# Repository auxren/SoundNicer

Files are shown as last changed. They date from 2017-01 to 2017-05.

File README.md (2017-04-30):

# SoundNicer
Eurorack Sound Nicer Module:

Maximizes the sonic potention of your modular signals.
Simple input and output with process and contour knobs.
Based off the CoolAudio V2153M

Version 1.1 Changes:
Changed resistor values to prevent clipping of incoming audio
Changed the potentiometer values and series resistors. Anything past 2'oclock starts to add distortion to the band.

Mouser cart: http://www.mouser.com/ProjectManager/ProjectDetail.aspx?AccessID=db3011bba3 
Still needs V2153, pots, and jacks.

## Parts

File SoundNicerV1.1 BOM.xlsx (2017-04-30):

Description | Designator | Distributor | Distributor_Pn | Mfr_Pn | Quantity | Comment
CAP | C1 | Mouser | 581-06032A101JAT2A | 06032A101JAT2A | 1 | 100pF
CAP | C2, C8, C9 | Mouser | 81-GRM188R61E225KA2D | GRM188R61E225KA12D | 3 | 2.2uF
CAP | C3 | Mouser | 581-06035A332JAT2A | 06035A332JAT2A | 1 | 3.3nF
CAP | C4, C6, C7 | Mouser | 81-GCM188R71E474KA4J | GCM188R71E474KA64J | 3 | 0.47uF
CAP | C5 | Mouser | 81-GRM188R71H333KA61 | GRM188R71H333KA61D | 1 | 33nF
CAP | C10, C12, C14, C15, C16 | Mouser | 581-MM035C104KCZ2A | MM035C104KCZ2A | 5 | 100nF
Aluminum Electrolytic Capacitor, UD Series, Low Impedance, 10 uF, 25 V, + / - 20%, -55 to 105 degC, Chip Type, 4 x 5.8 mm D x L, Pb-Free, Reel | C11, C13 | Mouser | 647-UUD1E100MCL | UUD1E100MCL1GS | 2 | 10uF
1.0 A Surface Mount Schottky Barrier Rectifier, 40 V, -65 to 125 degC, 2-Pin SOD-123 Package, RoHS, Tape and Reel | D1, D2 | Mouser | 621-1N5819HW-F | 1N5819HW-7-F | 2 | 1N5819HW-7-F
 | J1, J2 | Thonk |  |  | 2 | Thonkicon jack
Header, 5-Pin, Dual row | P1 | Mouser | 855-M20-9980545 |  | 1 | Header 5X2
Res | R1, R2, R7, R9, R10, R11, R12, R13, R14 | Mouser | 754-RG1608P-2152DT5 | RG1608P-2152-D-T5 | 9 | 21.5k
Res | R3, R4 | Mouser | 754-RR0816P-821D | RR0816P-821-D | 2 | 820
Res | R5 | Mouser | 754-RR0816P-103D | RR0816P-103-D | 1 | 10k
Res | R6 | Mouser | 754-RR0816P-1822D26C | RR0816P-1822-D-26C | 1 | 18.2k
Res | R8 | Mouser | 660-RK73H1JTTD3922F | RK73H1JTTD3922F | 1 | 39.2k
Res | R15 | Mouser | 660-RN73H1JT1062D100 | RN73H1JTTD1062D100 | 1 | 10.6k
Res | R16, R19 | Mouser | 754-RR0816P-753D | RR0816P-753D | 2 | 75k
Res | R17, R18 | Mouser | 754-RR0816P-104D | RR0816P-104-D | 2 | 100k
V2153 | U1 | Small Bear |  |  | 1 | V2153 Sound Enhancement IC
Dual Low-Noise JFET-Input General-Purpose Operational Amplifier, 7 to 36 V, -40 to 85 degC, 8-pin SOIC (D8), Green (RoHS & no Sb/Br) | U2 | Mouser | 511-TL072IDT | TL072IDT | 1 | TL072ID
Thonk Pot | VR1, VR2 |  |  |  | 2 | B10k

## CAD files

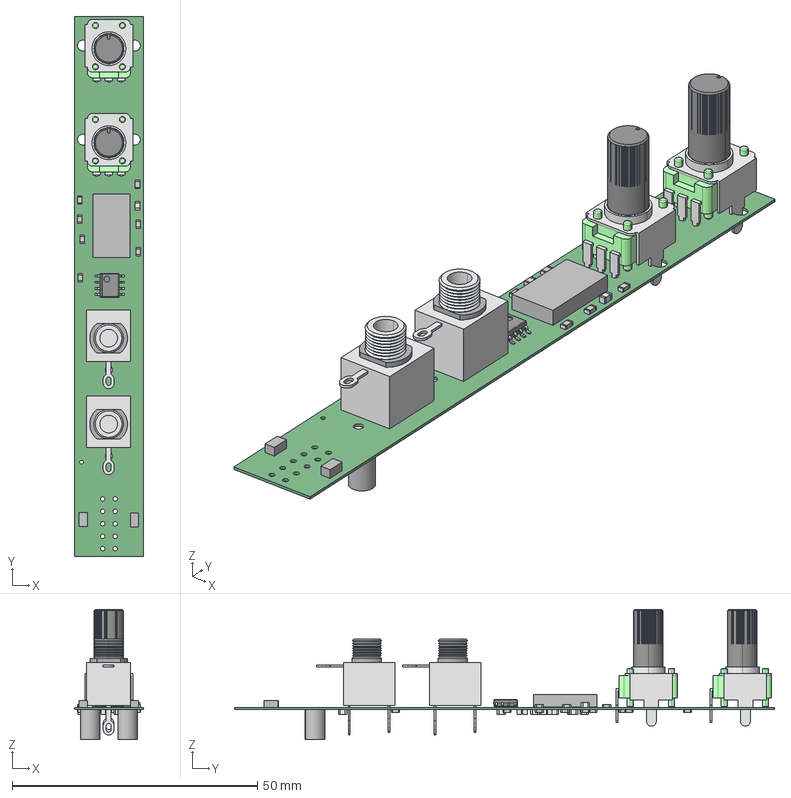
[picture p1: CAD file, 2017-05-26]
Sound Nicer Altium Project/SoundNicerPCB.step
14.2 x 110.2 x 26.5 mm
Board
9mmAlpha x 2
BODY_M08A_35
LEAD_M08A_57 x 8
MANIFOLD_SOLID_BREP_2784
MANIFOLD_SOLID_BREP_2935
MANIFOLD_SOLID_BREP_3086
MANIFOLD_SOLID_BREP_3237
Extruded x 102
mj-3507 x 2

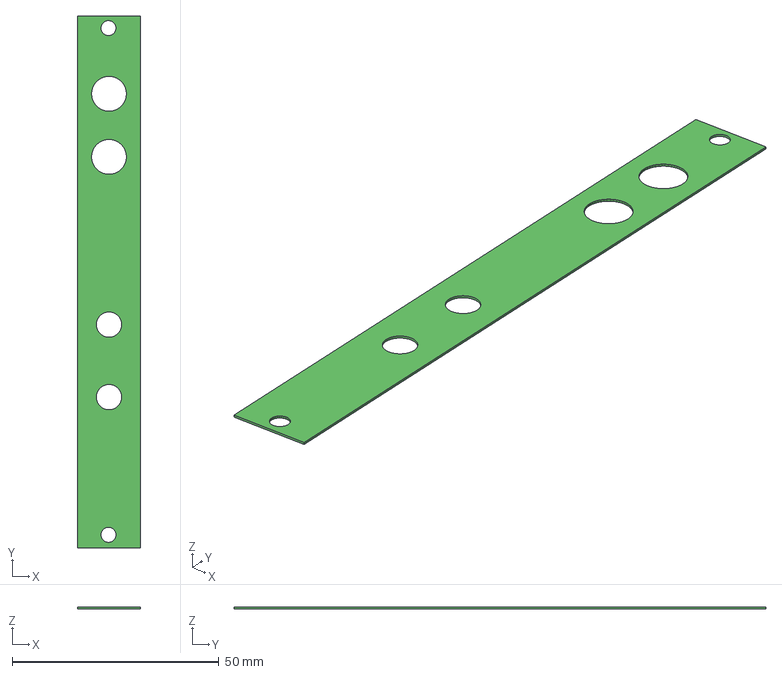
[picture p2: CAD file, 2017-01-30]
SoundNicerPanel/SoundNicerPanel.step
15.2 x 128.5 x 0.411 mm

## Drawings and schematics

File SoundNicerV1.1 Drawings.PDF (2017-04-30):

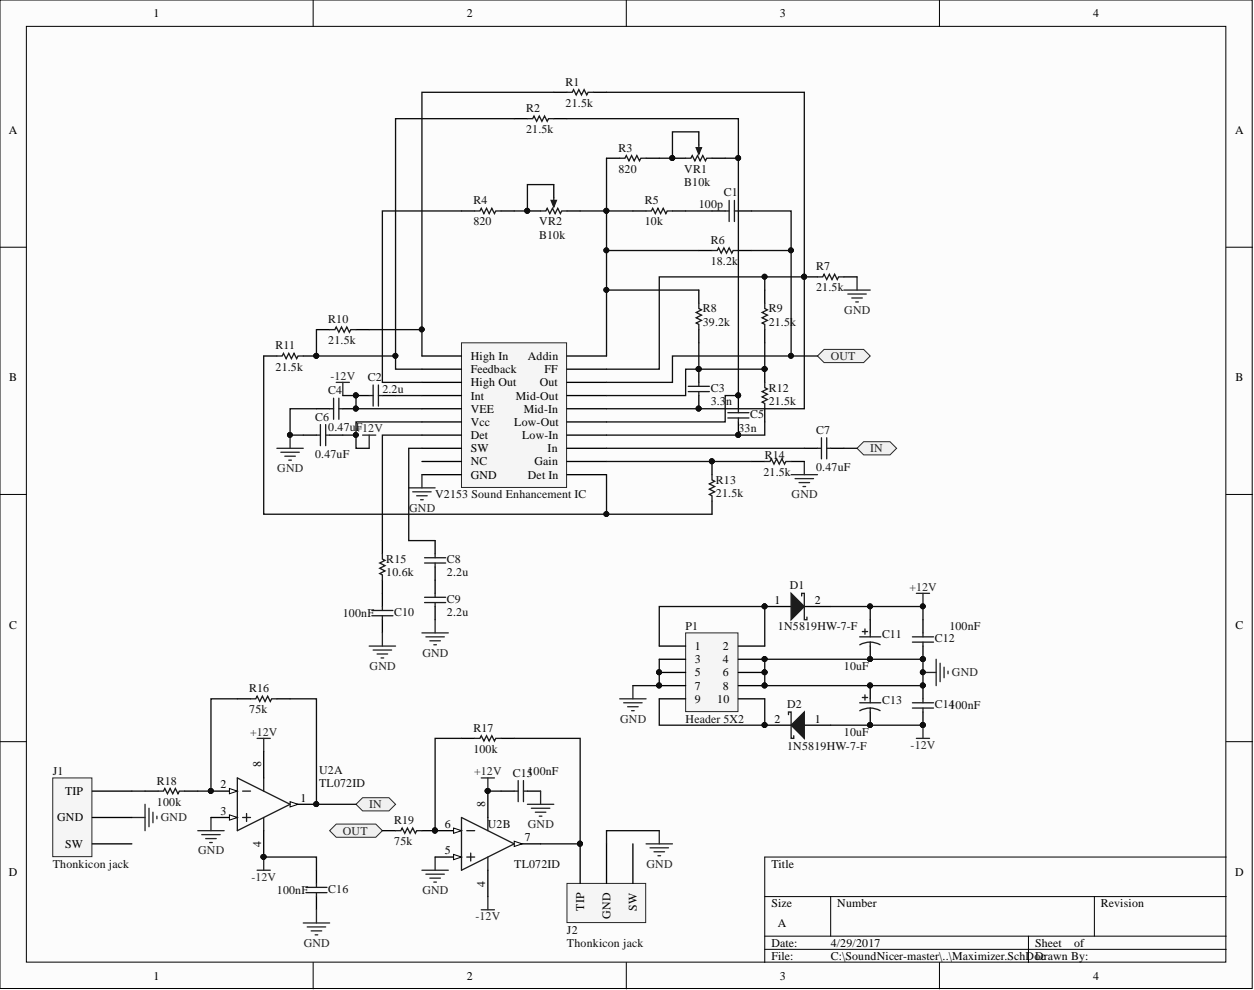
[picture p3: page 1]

High In

Out Mid-Out Mid-In Low-Out Low-In In Gain Det In

High Out Int VEE Vcc Det SW NC GND | | R12 21.5k

GND

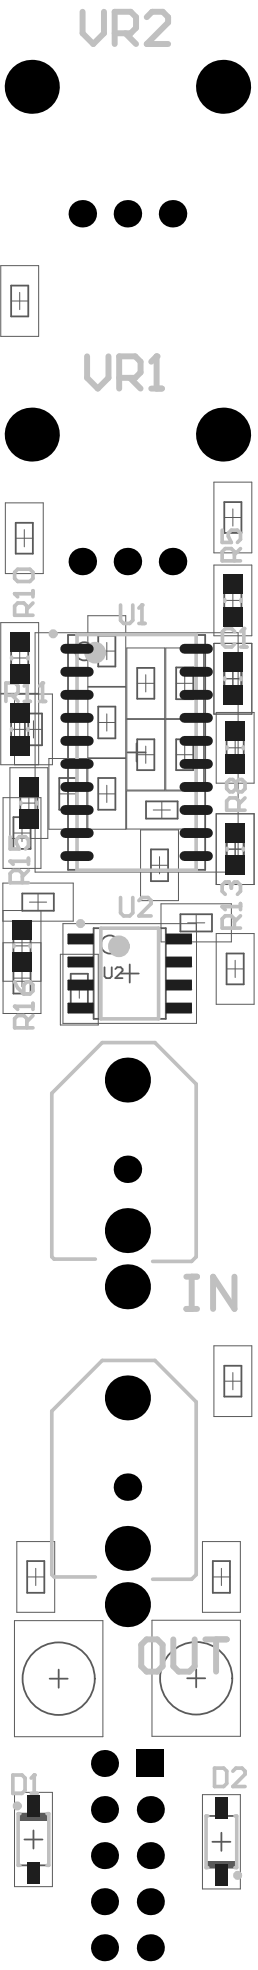
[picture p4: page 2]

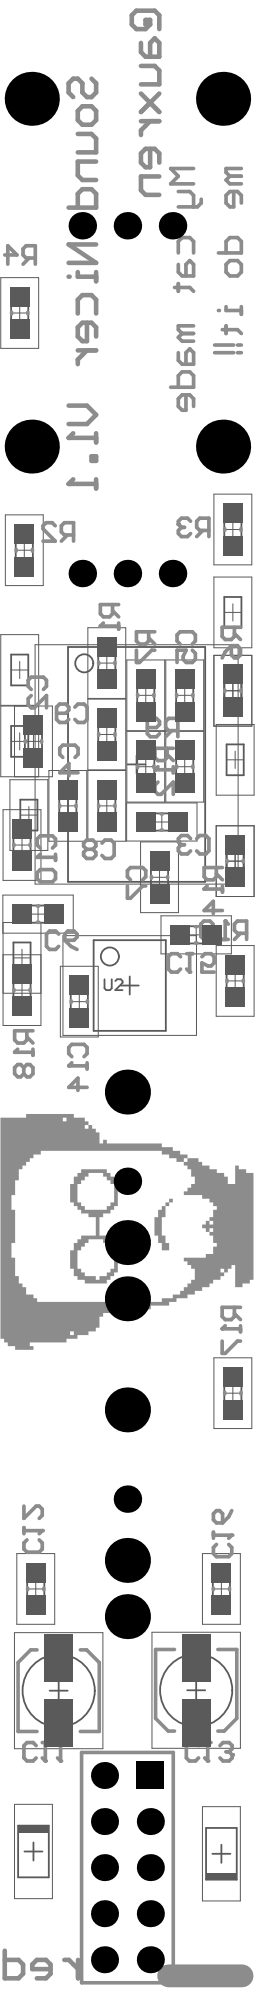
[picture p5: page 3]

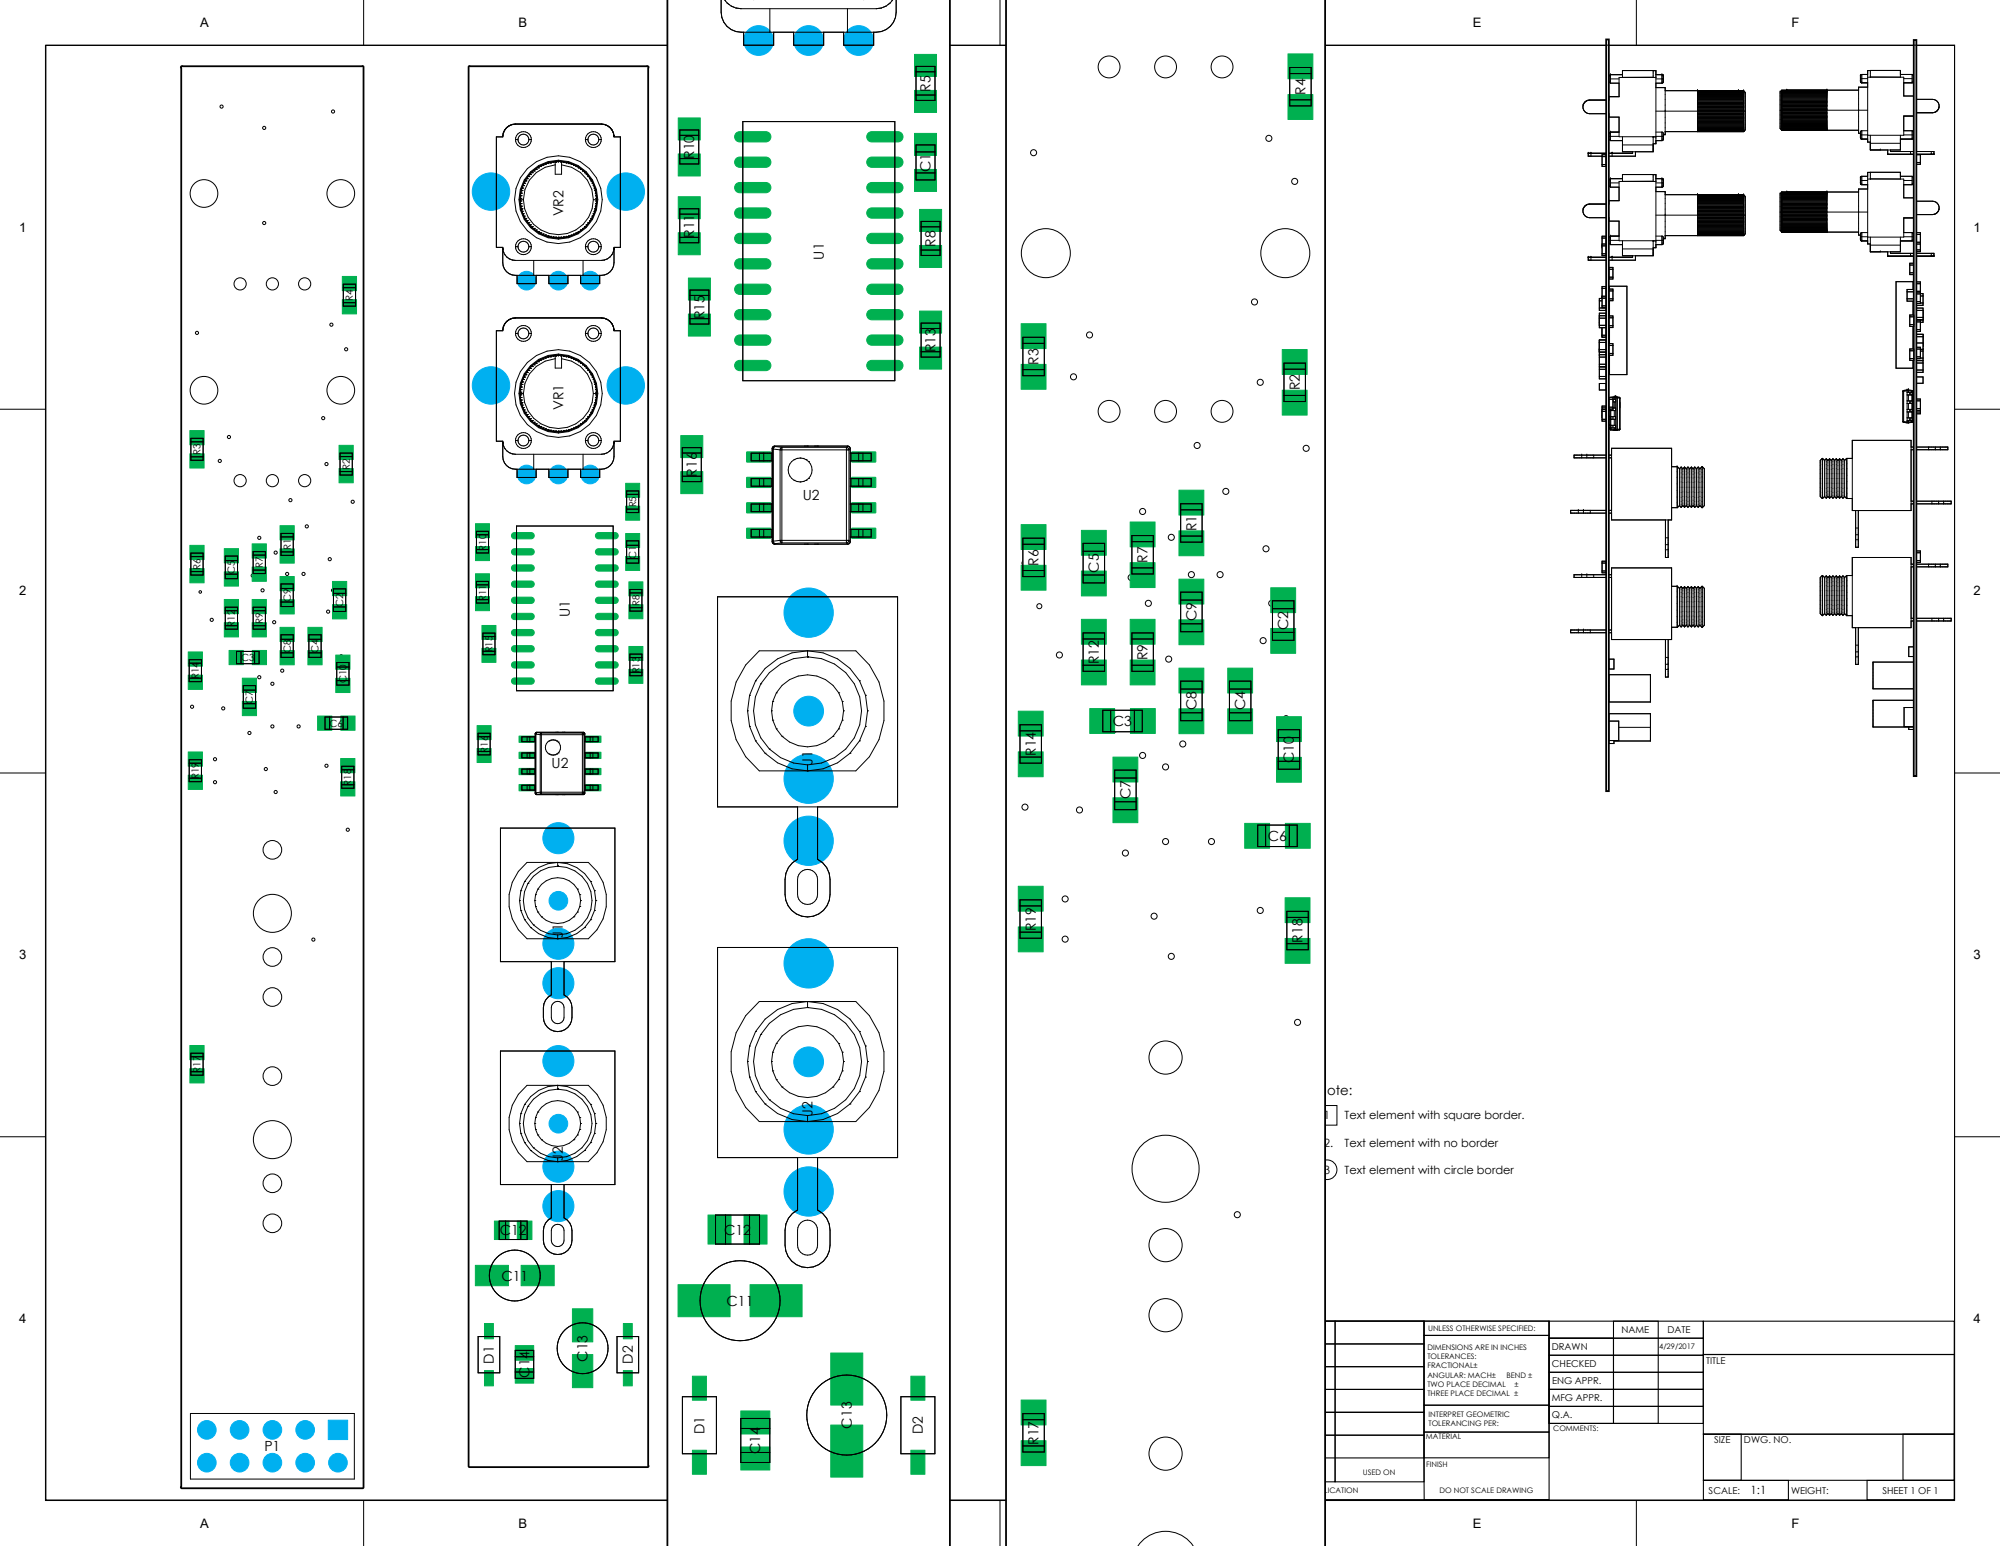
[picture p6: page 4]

2. Text element with no border 3 Text element with circle border

DIMENSIONS ARE IN INCHES
TOLERANCES:
FRACTIONAL±
ANGULAR: MACH± BEND ±
TWO PLACE DECIMAL ±
THREE PLACE DECIMAL ±

THE INFORMATION CONTAINED IN
THIS DRAWING IS THE SOLE
PROPERTY OF
. ANY REPRODUCTION IN PART
OR AS A WHOLE WITHOUT THE
WRITTEN PERMISSION OF IS
PROHIBITED.
PROPRIETARY AND CONFIDENTIAL

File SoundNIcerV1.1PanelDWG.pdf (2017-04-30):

A

B

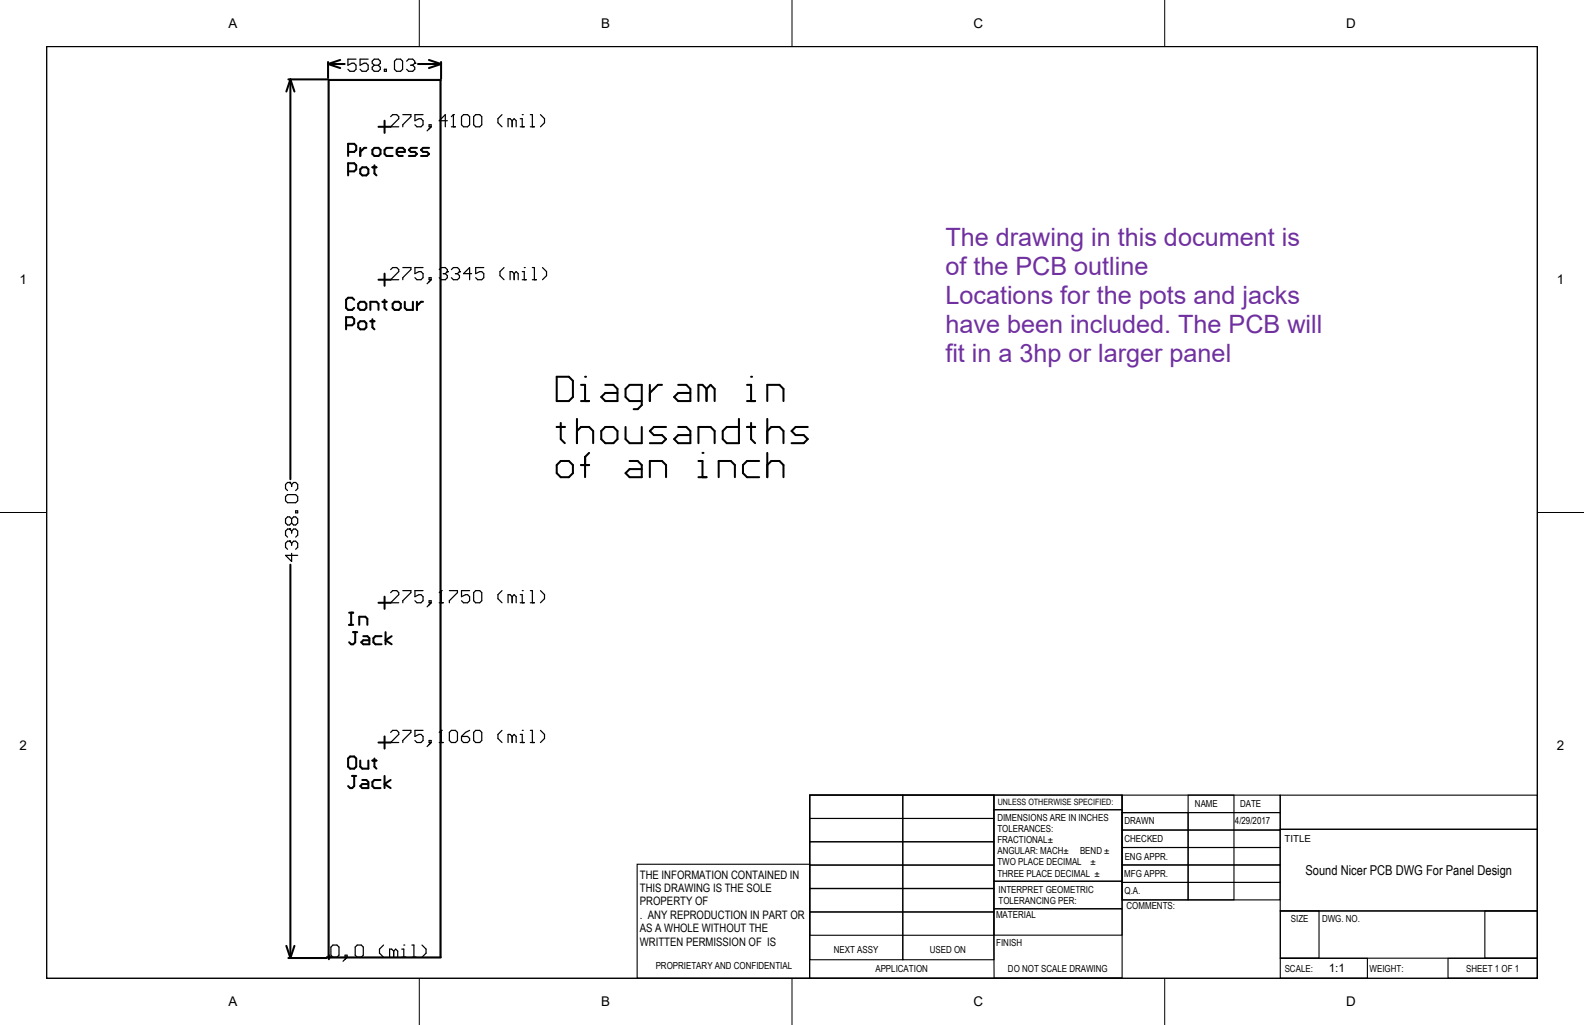
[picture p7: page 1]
DWG. NO.; COMMENTS:; FINISH; APPLICATION; DO NOT SCALE DRAWING; NEXT ASSY; USED ON; NAME; DATE; MFG APPR.; ENG APPR.; CHECKED; DRAWN; SCALE:; WEIGHT:; SHEET 1 OF 1; SIZE

The drawing in this document is
of the PCB outline
Locations for the pots and jacks
have been included. The PCB will
fit in a 3hp or larger panel

UNLESS OTHERWISE SPECIFIED:
DIMENSIONS ARE IN INCHES
TOLERANCES:
FRACTIONAL±
ANGULAR: MACH± BEND ±
TWO PLACE DECIMAL ±
THREE PLACE DECIMAL ±
INTERPRET GEOMETRIC
TOLERANCING PER:
MATERIAL

TITLE
Sound Nicer PCB DWG For Panel Design

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

PROPRIETARY AND CONFIDENTIAL

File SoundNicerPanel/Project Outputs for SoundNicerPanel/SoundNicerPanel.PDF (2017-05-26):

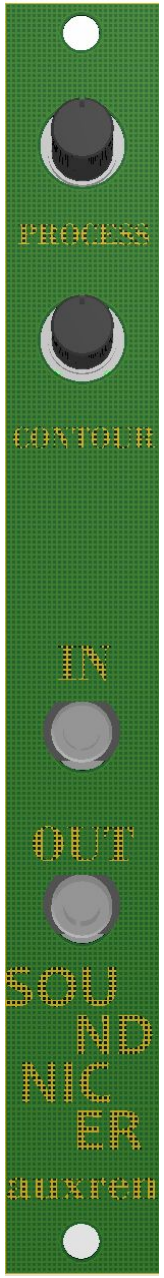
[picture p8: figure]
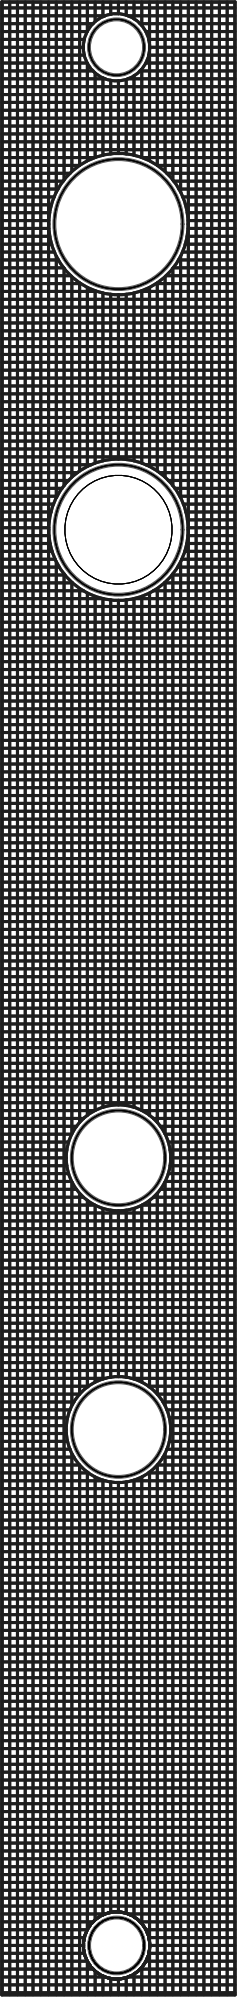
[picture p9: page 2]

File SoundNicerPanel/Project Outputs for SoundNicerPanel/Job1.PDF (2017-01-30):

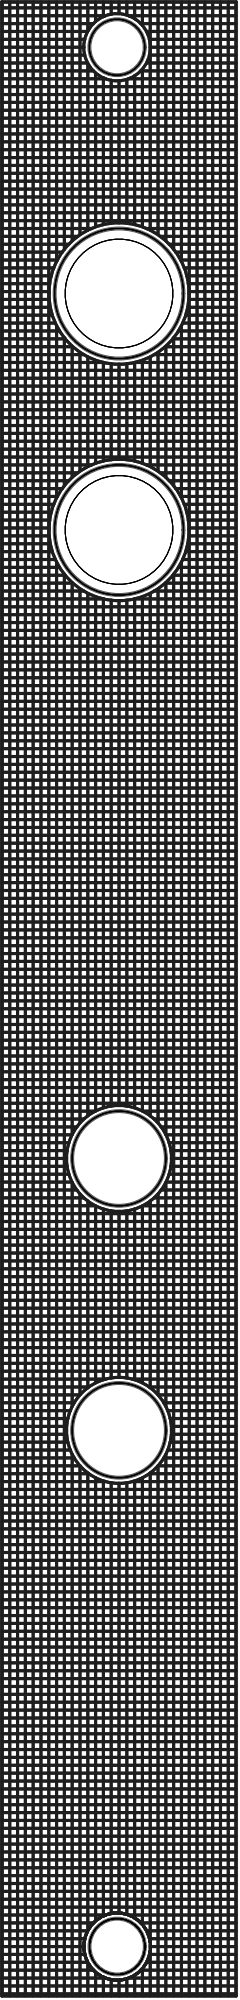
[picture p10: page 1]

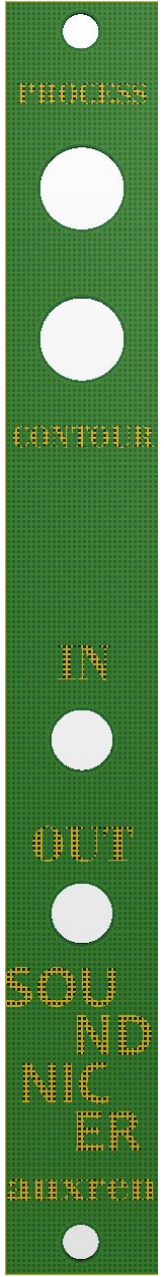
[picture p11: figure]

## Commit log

2016-12-16 Sound Nicer PCB and Fab Files added V1
    [Maximizer.SchDoc, SonicMaximizer.PrjPcb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]
2016-12-16 Added Schematic/Assembly Drawing
2016-12-16 Tented Vias
    [SoundNicerPCB.PcbDoc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]
2016-12-19 Added Bom
    Cleaned up BOM and added it to Github
    [Maximizer.SchDoc, SonicMaximizer.PrjPcb, SoundNicer.xlsx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]
2017-01-13 Screwed up on the first PCB, this should be good (iHope)
    [SonicMaximizer.PrjPcb, SoundNicerPCB.PcbDoc]
2017-01-13 Cleaning up
    [SoundNicer.GBL, SoundNicer.GBO, SoundNicer.GBP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]
2017-01-13 cleaning more
    [Maximizer.SchDoc, SoundNicer.xlsx]
2017-01-17 Cleaned up
    Moved files around, cleaned the fab files. Added PnP files just incase
    [SonicMaximizer.PrjPcb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]
2017-01-30 Added Panel
    Added panel files and cleaned up bom
    [SoundNicer BOM.xlsx, SoundNicerPCB.PcbDoc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]
2017-01-30 Added Annotation to Gerbers
    [SoundNicer.GBL, SoundNicer.GBO, SoundNicer.GBP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]
2017-02-21 Fixed Bom issue with C12 and C14
    Fixed Bom issue with C12 and C14
    [SoundNicer BOM.xlsx]
2017-04-30 V1.1 Release
    Rotated Power Header
    Fixed a few footprints
    Added decoupling caps to Op-Amp rails
    Moved knobs
    Changed some resistor values
    [Maximizer.SchDoc, PanelCoordinate.PcbDoc, SonicMaximizer.PrjPcb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]
2017-05-26 Added updated panel
    Moved pot around for panel
    [SoundNicerPCB.step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]
